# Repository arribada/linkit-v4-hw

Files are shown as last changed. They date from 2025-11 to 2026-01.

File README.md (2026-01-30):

N|Solid

Collaboration with 

N|Solid

# Altium project for Linkit-v4 product

Linkit V4 is the fourth generation of the Linkit tracker CORE board, developed in collaboration with CLS (Collecte Localisation Satellites). This revision transitions from the discontinued ARTIC R3 transceiver to next-generation satellite communication modules, ensuring long-term availability for Argos/Kineis satellite networks.

## Hardware Variants

This project contains **two hardware variants** maintained in separate branches:

### linkit-v4-kim (Branch: `linkit-v4-kim`)
Based on the **KIM2 module** from CLS/Kineis for satellite uplink communication.
- Uses KIM2 satellite modem module
- Certified for Kineis satellite network
- See KIM2 Integration Manual (contact CLS)

### linkit-v4-smd (Branch: `linkit-v4-smd`)
Based on the **Argos-SMD module** - an open-source alternative.
- Compatible with Arribada's Argos-SMD hardware: https://github.com/arribada/argos-smd-hw
- Provides flexibility for custom satellite communication implementations
- Additional power management circuitry for SMD module
- Check [argos-smd-hw repository](github.com/arribada/argos-smd-hw)

The master branch contains a board with both footprints on the same layout, but it is not up to date and may be missing recent changes (deprecated branch).

## Features

### Core Specifications
- **MCU**: ISP1807 (nRF52840-based module)
- **GNSS**: u-blox SAM-M10Q with integrated ceramic antenna
- **Flash Memory**: IS25LP128F (128 Mbit NOR Flash)
- **IMU**: BMA400 ultra-low power accelerometer
- **ADC**: ADS1115 16-bit, 4-channel (for external sensors)

### Power Management
- **Battery**: Single-cell Li-Ion/LiPo (3.7V, 4.2V max)
- **Charging Options**:
  - USB Type-C (BQ25176M linear charger, 800mA)
  - Qi Wireless charging (BQ51003, 2.5W)
  - Solar panel input (3-18V via BQ25176M MPPT-compatible input)
- **Voltage Regulation**: 
  - TPS63901 Buck/Boost (configurable 1.8V/3.3V for main system)
  - TPS612997 Buck/Boost (3.6V for satellite module - SMD variant)
  - TPS22960 dual load switches for power domain control
- **Ultra-low power design**: Sub-microamp quiescent current in sleep modes

### Connectivity & Interfaces
- **Satellite Communication**: KIM2 or Argos-SMD module (variant-dependent)
- **GNSS**: Integrated u-blox M10Q receiver
- **External I/O**:
  - 8-pin expansion connector (1.25mm pitch)
  - External I2C bus for sensors
  - Salt-water switch (SWS) interface
  - Battery voltage monitoring
  - Pressure sensor support via ADC channels
- **Programming/Debug**: 
  - Dual JTAG connectors (ISP1807 + Satellite module)
  - USB-C for firmware updates and charging

### Physical
- Compact form factor optimized for marine deployments
- Reed switch for magnetic activation
- Tri-color LED status indicator
- U.FL/SMA antenna connector options

## Configuration Options

No jumper directly on board, represented by component Resistors or Diode.

### Power Source Selection
The board supports multiple power configurations via resistor options:

1. **Standard Operation** (Default):
   - Battery + USB/Wireless charging + optional solar input
   - All power sources can coexist safely

2. **USB-Only Power** (No Battery):
   - Configuration: R53=DNP, R52=Fitted, R55=Fitted
   - ⚠️ **Warning**: Do NOT connect battery in this mode
   - ⚠️ **Warning**: Power LED D2 incompatible with 5V - cut trace O9 (Not critical)

### Voltage Selection
- **PSEL Pin (TPS63901)**: Switches between 1.8V and 3.3V system voltage
  - Low = 2.3V (minimum voltage for IS25LP Flash and ADC)
  - High = 3.3V (default for most operations)

### Reed Switch
- Magnetic activation via P-channel MOSFET (Q4)
- Can be controlled via MCU or magnetically triggered
- 3.3V logic level compatible

## Operating Modes

### Charging Modes
The tri-color LED (D2) indicates charging status:
- **OFF**: Battery only, no charging
- **Yellow**: Charging via USB
- **White/Cyan**: Charging via wireless coil
- **Green**: Fully charged
- **Blinking Green**: Fault condition (thermal, timer, over-voltage)

## Firmware (still in development)
Firmware is not released as open source at the moment.
- Firmware based on Linkit-v3 Baremetal : https://github.com/arribada/linkit-v4-core
- Zephyr firmware : https://github.com/arribada/linkitv4

## Hardware References (Previous Versions)

Linkit V4 is the successor of previous Linkit CORE board generations developed by Arribada.  
Earlier versions were based on different satellite transceivers and power architectures.

- **Linkit V3**
  - Based on the ARTIC R2/R3 satellite transceiver (now discontinued)
  - Earlier GNSS and power management architectures
  - Designed for Argos satellite network compatibility
  - Links:
    - Hardware github : https://github.com/arribada/CLS-Argos-Linkit-Hardware/
    - Firmware project : [CLS-Argos-Linkit-CORE](https://github.com/arribada/CLS-Argos-Linkit-CORE)
    - Python application : [CLS-Argos-Linkit-pylinkit](https://github.com/arribada/CLS-Argos-Linkit-pylinkit)
    - Phone application : [GenTracker](https://play.google.com/store/apps/details?id=com.trackgen&hl=fr&gl=US&pli=1) available on the store

These earlier designs are no longer actively maintained but are provided for reference and historical context.

## Known Issues & Design Notes

### Issues to Address in Next Revision

⚠️ The **Issues** section of this GitHub repository lists all fixes that need to be applied for the next batch, or by anyone who wants to design or reuse parts of this project.

## License

This project contains hardware design files only.

All hardware design files (schematics, PCB layouts, Altium project files)
are licensed under the **CERN Open Hardware Licence v1.2 (CERN-OHL v1.2)**.

See the `LICENSE` file for the full license text.

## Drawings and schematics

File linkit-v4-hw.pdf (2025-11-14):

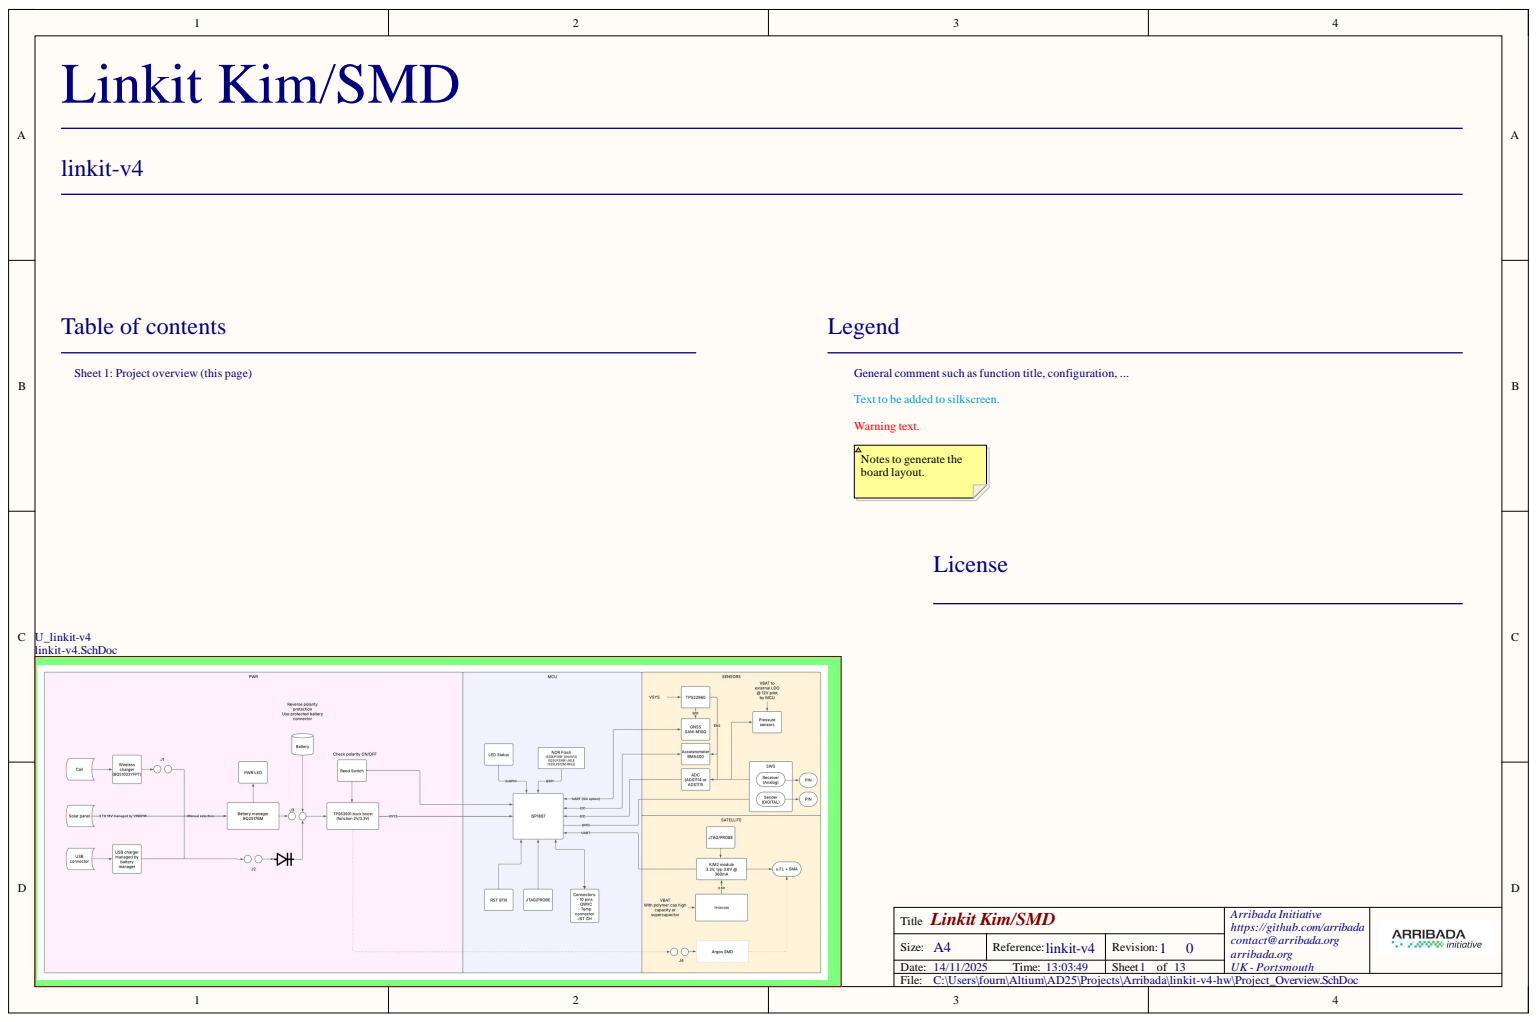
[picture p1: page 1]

Sheet 1: Project overview (this page)

General comment such as function title, configuration, ...

Text to be added to silkscreen.

Notes to generate the
board layout.

Arribada Initiative
https://github.com/arribada
contact@arribada.org
arribada.org

C:\Users\fourn\Altium\AD25\Projects\Arribada\linkit-v4-hw\Project_Overview.SchDoc

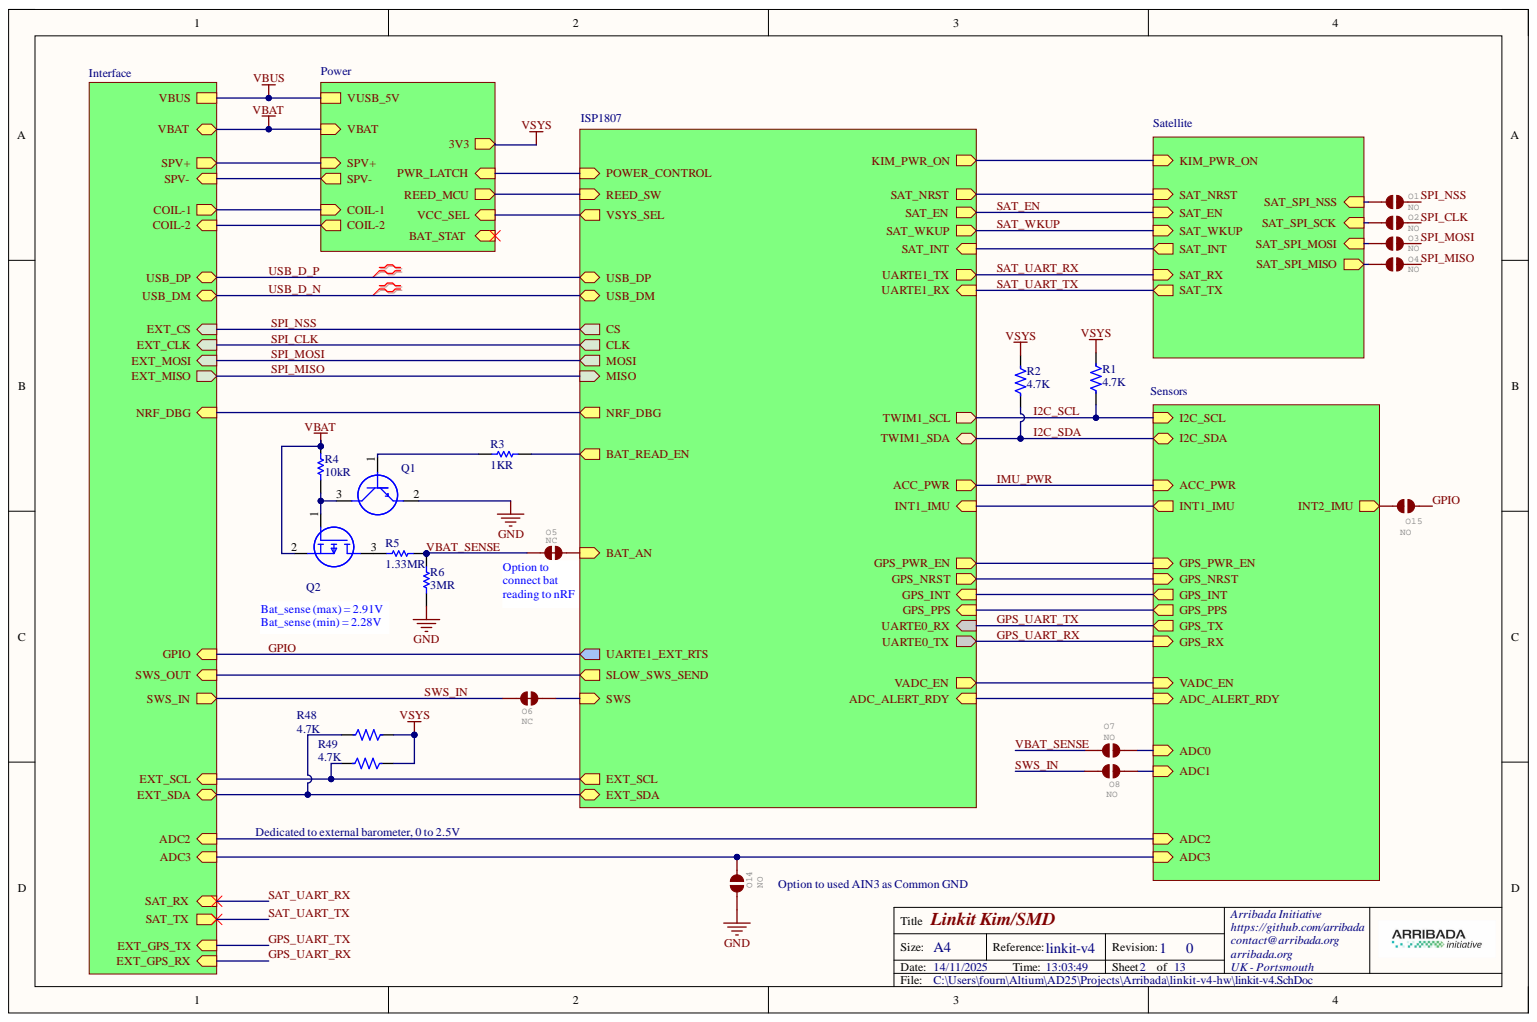
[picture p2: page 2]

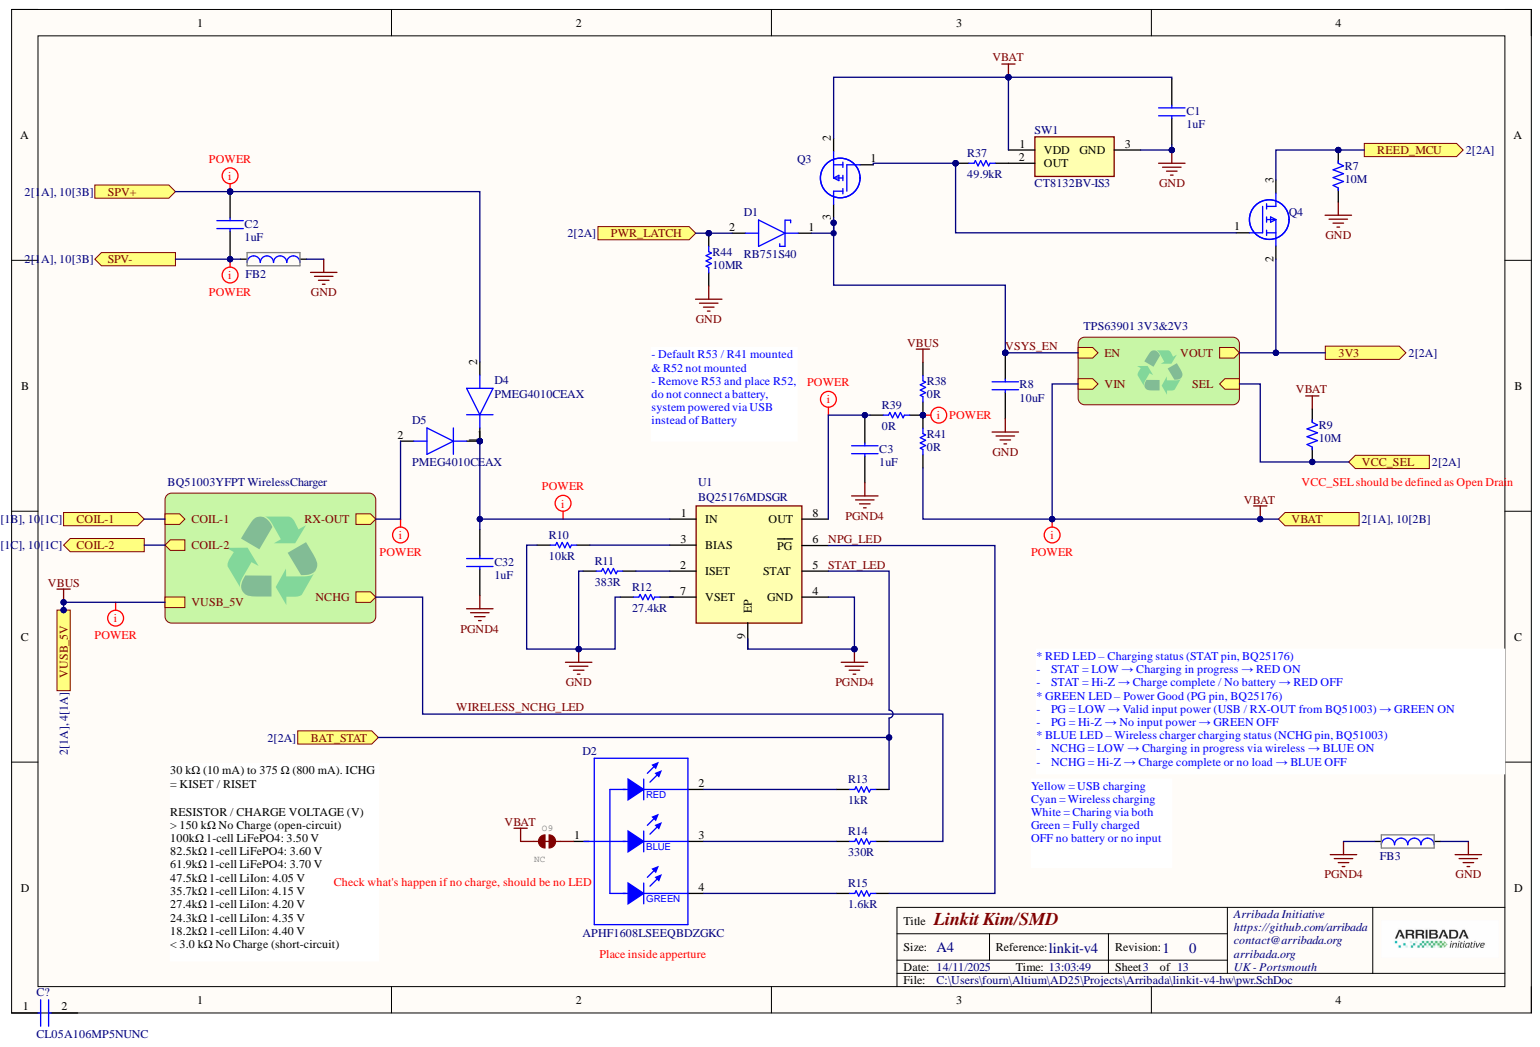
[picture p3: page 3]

& R52 not mounted
- Remove R53 and place R52,
do not connect a battery,
system powered via USB
instead of Battery

VCC_SELshould be defined as Open Drain

* RED LED – Charging status (STAT pin, BQ25176)
- STAT = LOW → Charging in progress → RED ON
- STAT = Hi-Z → Charge complete / No battery → RED OFF
* GREEN LED – Power Good (PG pin, BQ25176)
- PG = LOW → Valid input power (USB / RX-OUT from BQ51003) → GREEN ON
- PG = Hi-Z → No input power → GREEN OFF
* BLUE LED – Wireless charger charging status (NCHG pin, BQ51003)
- NCHG = LOW → Charging in progress via wireless → BLUE ON
- NCHG = Hi-Z → Charge complete or no load → BLUE OFF

30 kΩ (10 mA) to 375 Ω (800 mA). ICHG
= KISET / RISET

Yellow = USB charging
Cyan = Wireless charging
White = Charing via both
Green = Fully charged
OFF no battery or no input

RESISTOR / CHARGE VOLTAGE (V)
> 150 kΩ No Charge (open-circuit)
100kΩ 1-cell LiFePO4: 3.50 V
82.5kΩ 1-cell LiFePO4: 3.60 V
61.9kΩ 1-cell LiFePO4: 3.70 V
47.5kΩ 1-cell LiIon: 4.05 V
35.7kΩ 1-cell LiIon: 4.15 V
27.4kΩ 1-cell LiIon: 4.20 V
24.3kΩ 1-cell LiIon: 4.35 V
18.2kΩ 1-cell LiIon: 4.40 V
< 3.0 kΩ No Charge (short-circuit)

Check what's happen if no charge, should be no LED

Linkit Kim/SMD Title | Arribada Initiative https://github.com/arribada contact@arribada.org arribada.org

A4 Size: | Reference: linkit-v4 | 0 Revision: 1

C:\Users\fourn\Altium\AD25\Projects\Arribada\linkit-v4-hw\pwr.SchDoc

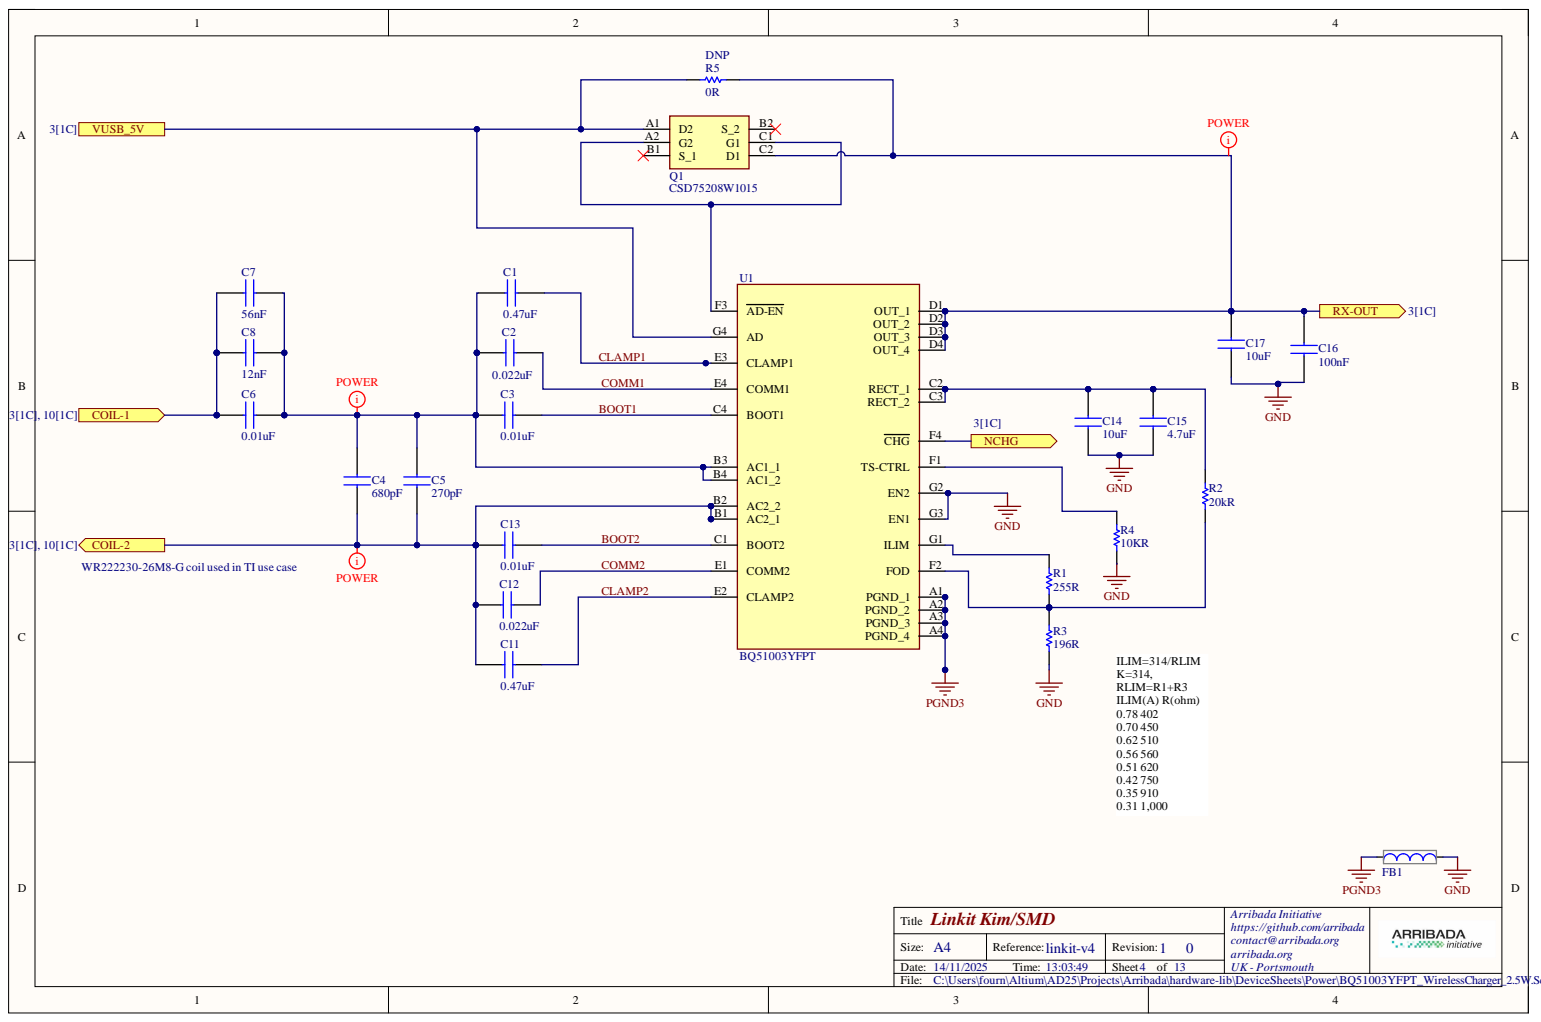
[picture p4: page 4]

CLAMP1

COMM1 | | COMM1 E4

BOOT1 C4 | 3[1C] C14 | C15 4.7uF

BOOT2 C1 | GND | R4 10KR 255R GND

WR222230-26M8-G coil used in TI use case

0.01uF | COMM2 | COMM2 E1

CLAMP2 | | CLAMP2 E2

Arribada Initiative
https://github.com/arribada
contact@arribada.org
arribada.org

C:\Users\fourn\Altium\AD25\Projects\Arribada\hardware-lib\DeviceSheets\Power\BQ51003YFPT_WirelessCharger_2.5W.SchDoc

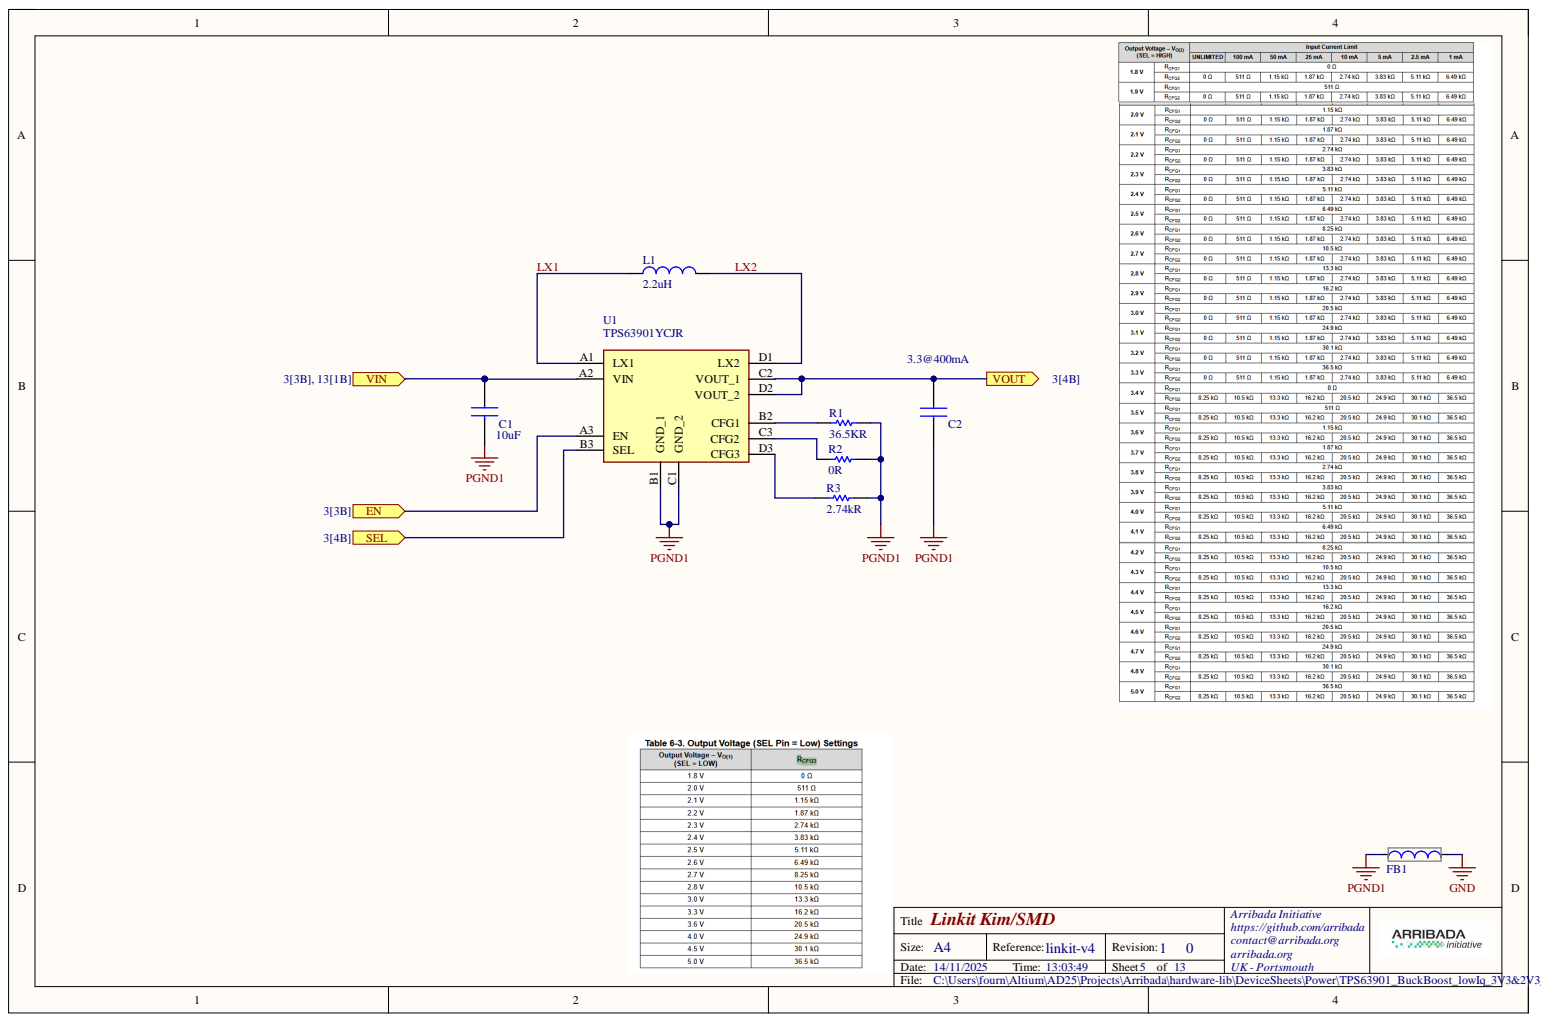
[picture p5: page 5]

Arribada Initiative
https://github.com/arribada
contact@arribada.org
arribada.org

C:\Users\fourn\Altium\AD25\Projects\Arribada\hardware-lib\DeviceSheets\Power\TPS63901_BuckBoost_lowIq_3V3&2V3_400mA.SchDoc

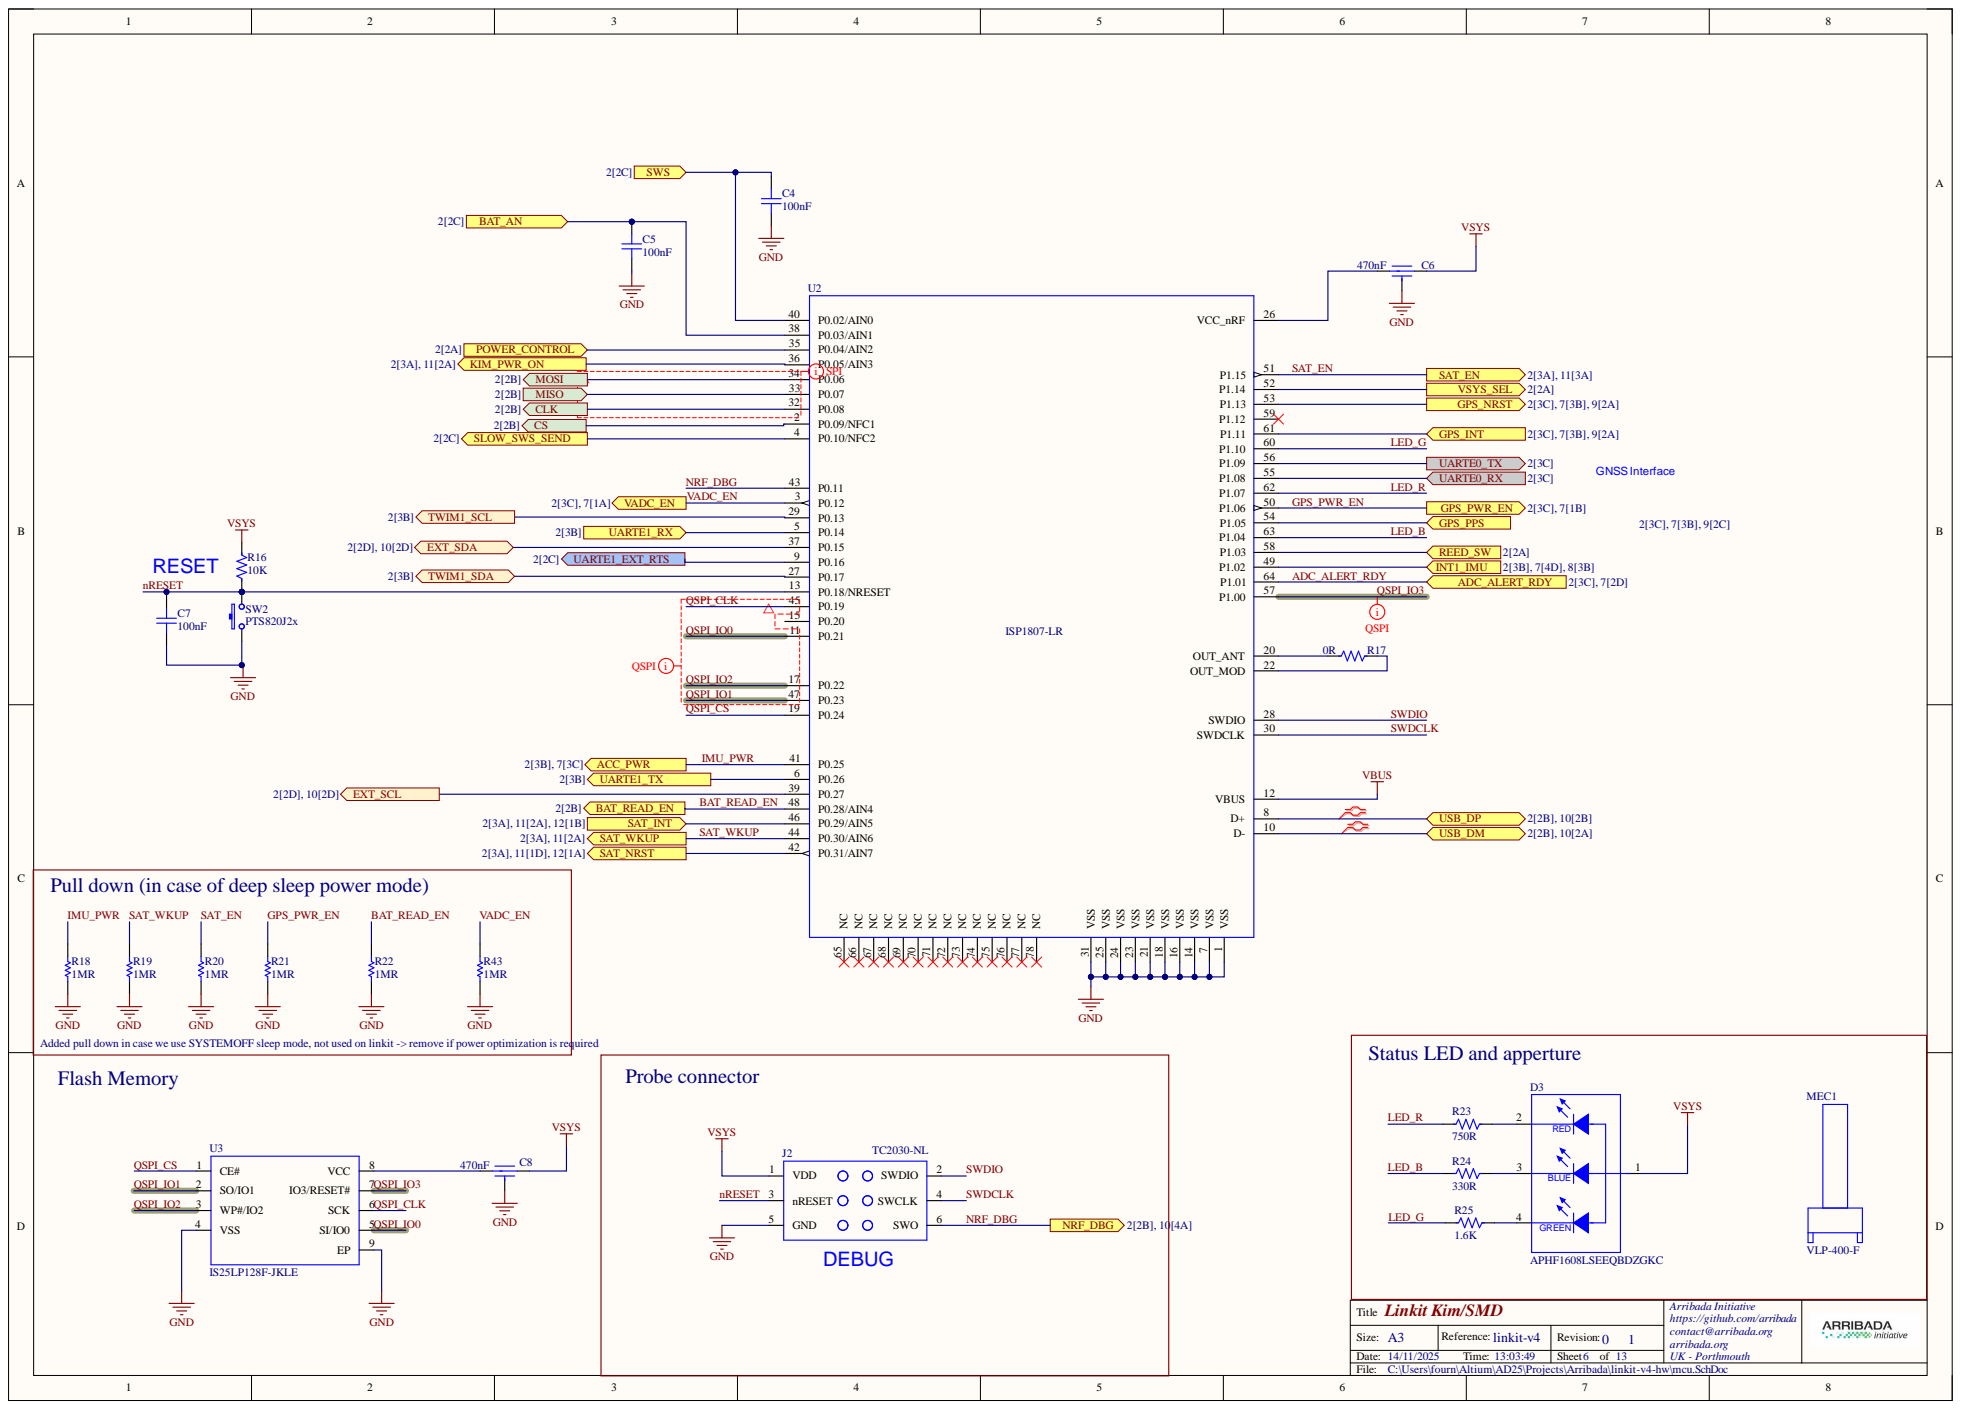
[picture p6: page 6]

Pull down (in case of deep sleep power mode)

GND
Added pull down in case we use SYSTEMOFF sleep mode, not used on linkit -> remove if power optimization is required
Flash Memory

Status LED and apperture

Linkit Kim/SMD Title | Arribada Initiative https://github.com/arribada contact@arribada.org arribada.org UK - Porthmouth

Size: A3 | Reference: linkit-v4 | Revision: 0 1

C:\Users\fourn\Altium\AD25\Projects\Arribada\linkit-v4-hw\mcu.SchDoc

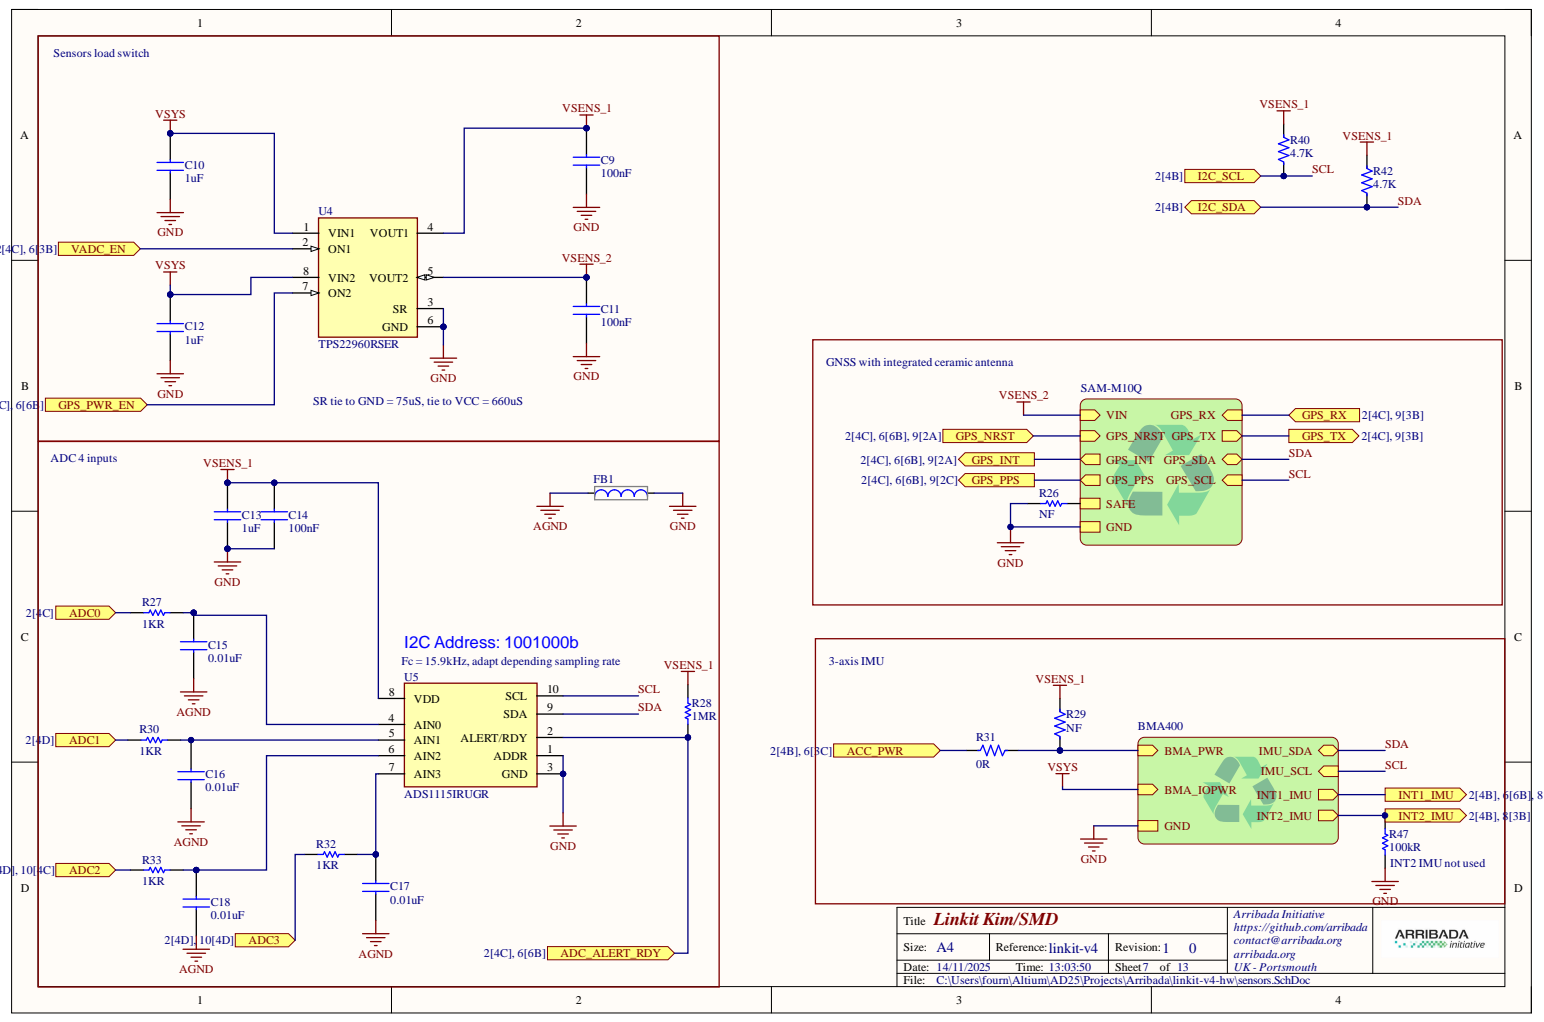
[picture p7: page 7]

GNSS with integrated ceramic antenna

SR tie to GND = 75uS, tie to VCC = 660uS

Linkit Kim/SMD Title | Arribada Initiative https://github.com/arribada contact@arribada.org arribada.org

A4 Size: | Reference: linkit-v4 | 0 Revision: 1

C:\Users\fourn\Altium\AD25\Projects\Arribada\linkit-v4-hw\sensors.SchDoc

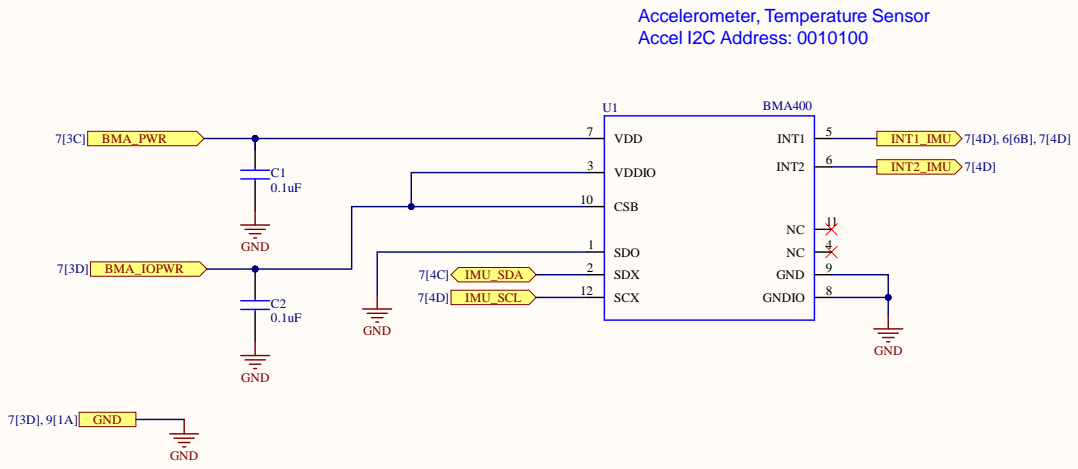
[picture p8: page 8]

7[4 C ] IMU _SD A 1

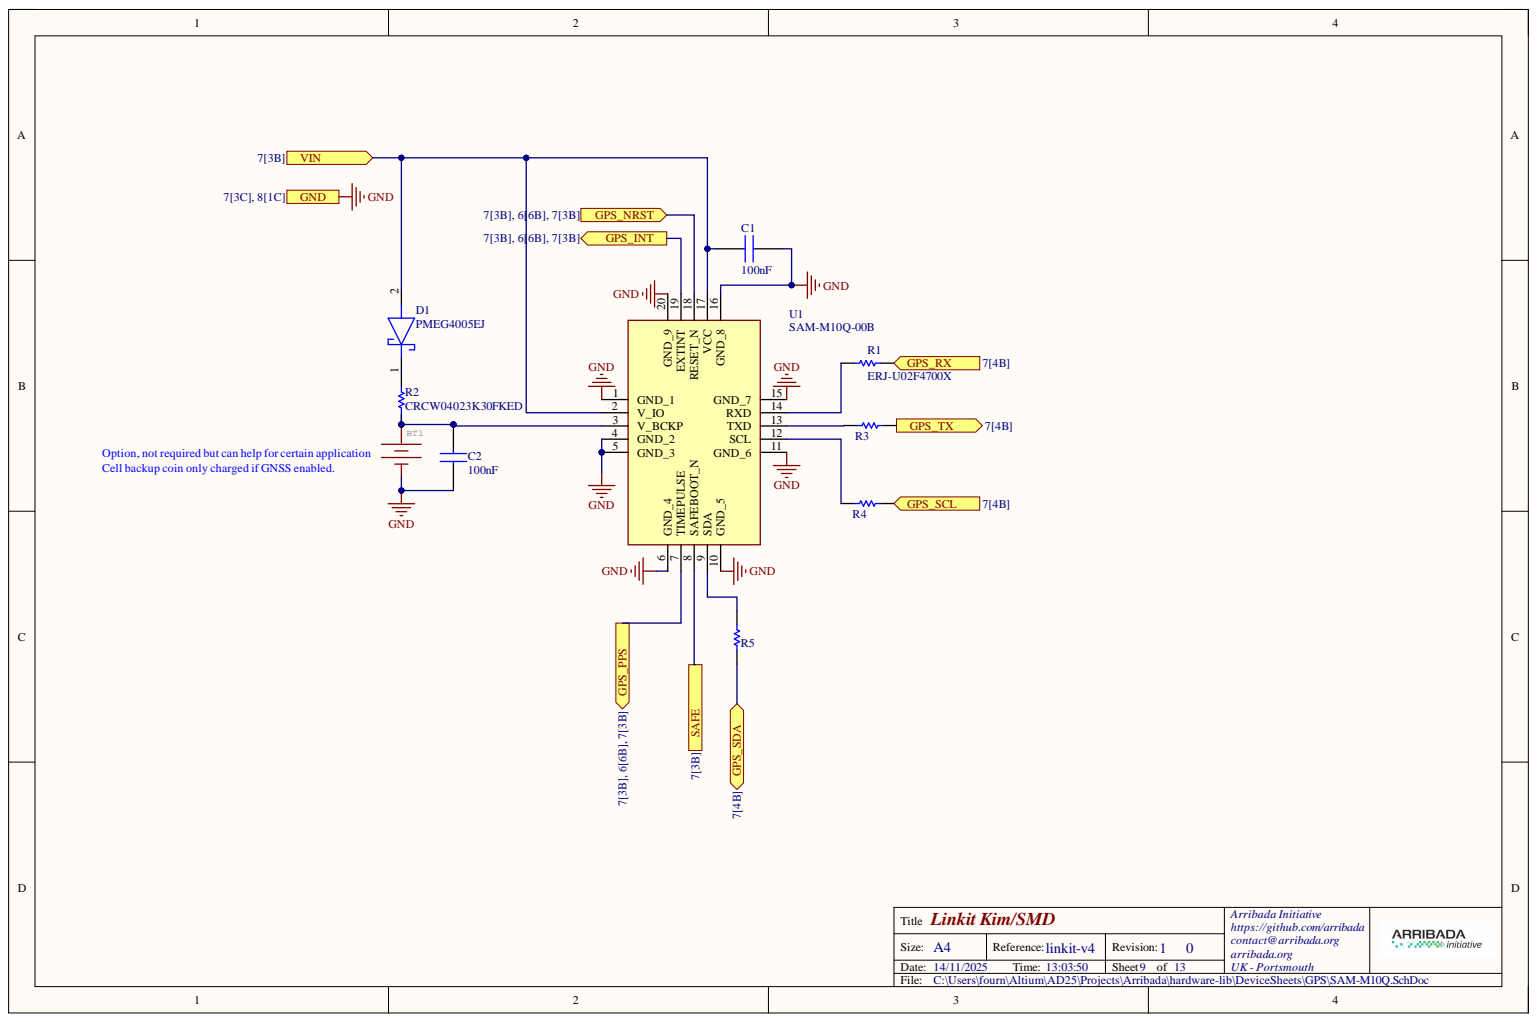
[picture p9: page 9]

D1 PMEG4005EJ R2 CRCW04023K30FKED

V_BCKP 3

Option, not required but can help for certain application
Cell backup coin only charged if GNSS enabled.

Arribada Initiative
https://github.com/arribada
contact@arribada.org
arribada.org

C:\Users\fourn\Altium\AD25\Projects\Arribada\hardware-lib\DeviceSheets\GPS\SAM-M10Q.SchDoc

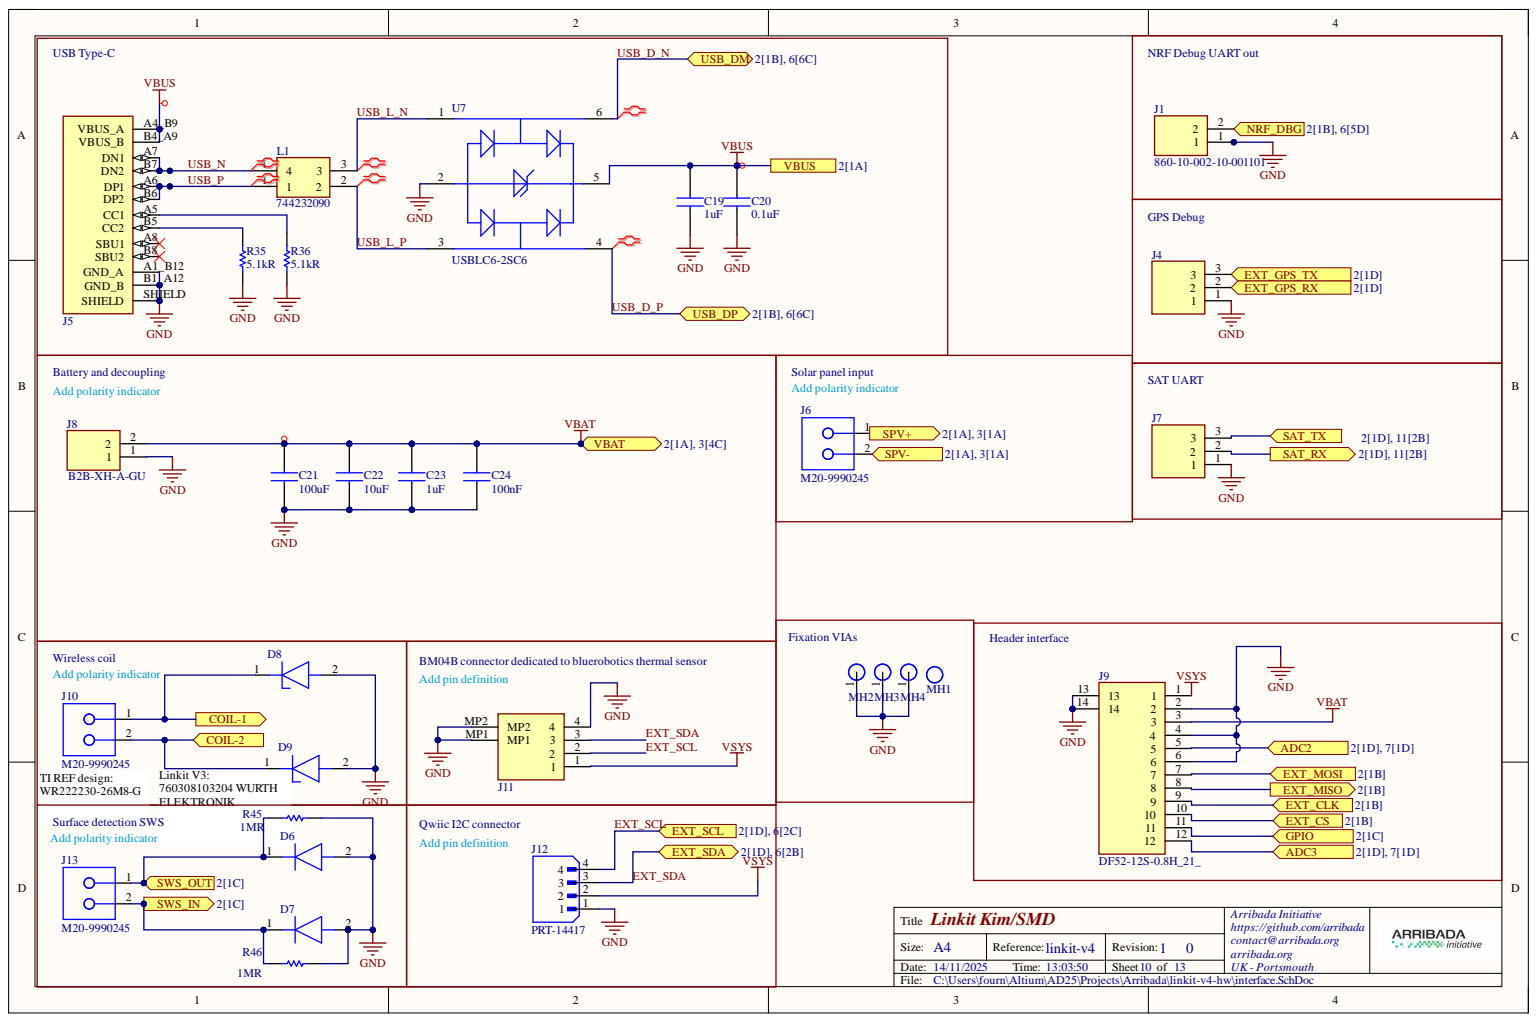
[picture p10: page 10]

NRF Debug UART out

BM04B connector dedicated to bluerobotics thermalsensor
Add pin definition

Arribada Initiative
https://github.com/arribada
contact@arribada.org
arribada.org

C:\Users\fourn\Altium\AD25\Projects\Arribada\linkit-v4-hw\interface.SchDoc

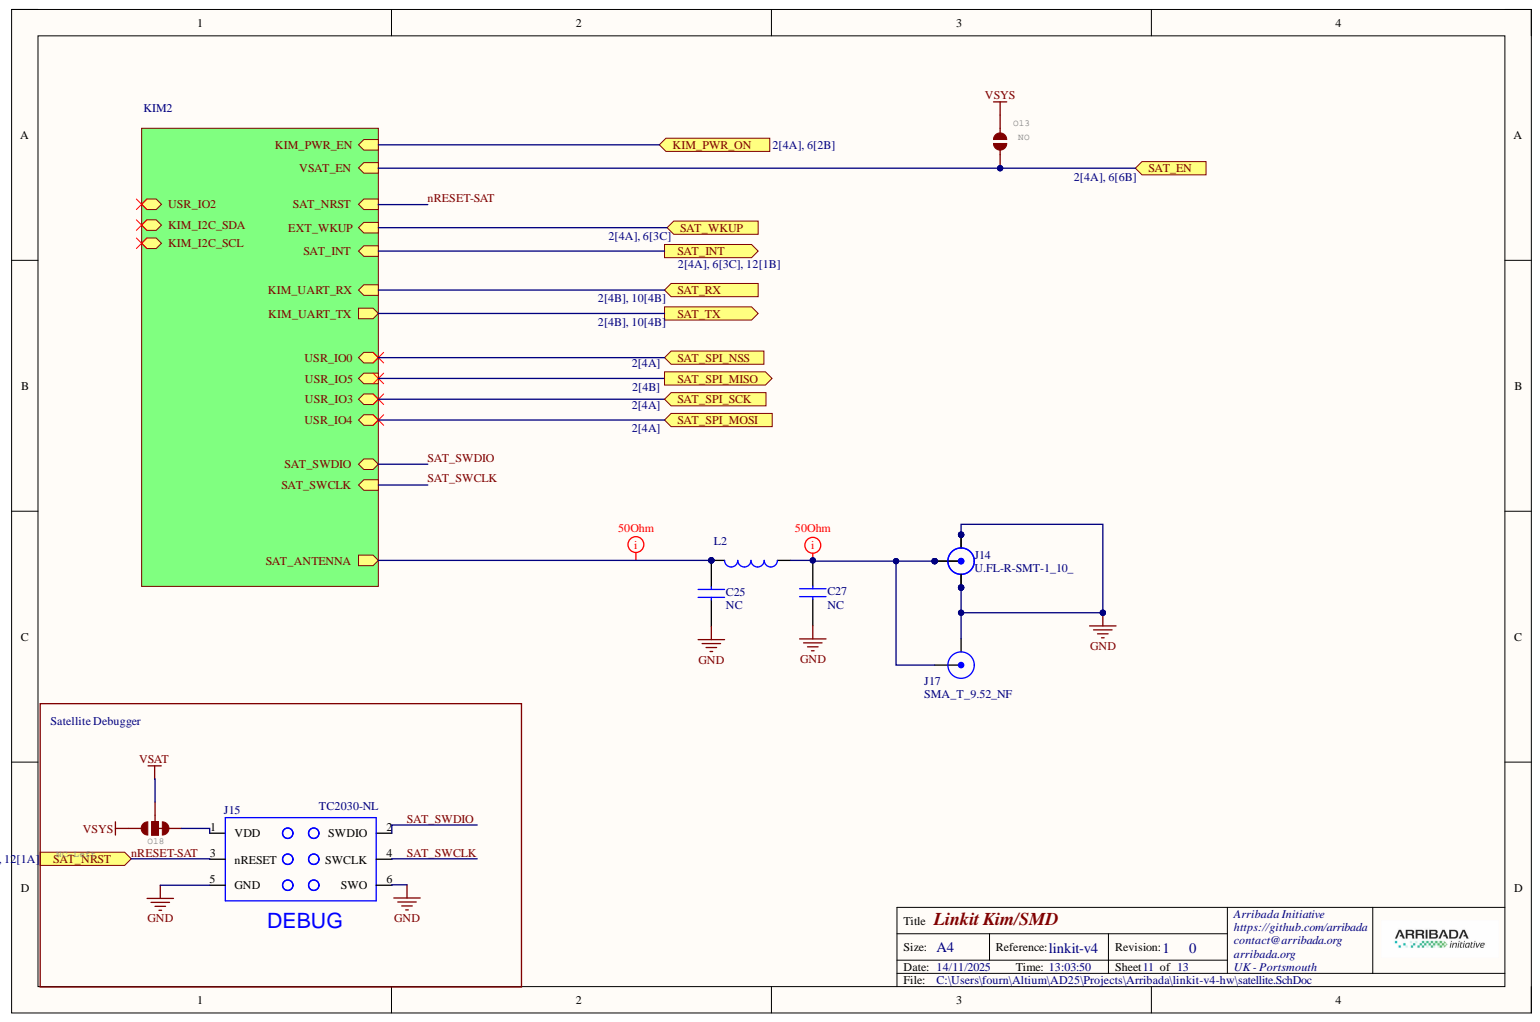
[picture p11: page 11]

Arribada Initiative
https://github.com/arribada
contact@arribada.org
arribada.org

C:\Users\fourn\Altium\AD25\Projects\Arribada\linkit-v4-hw\satellite.SchDoc

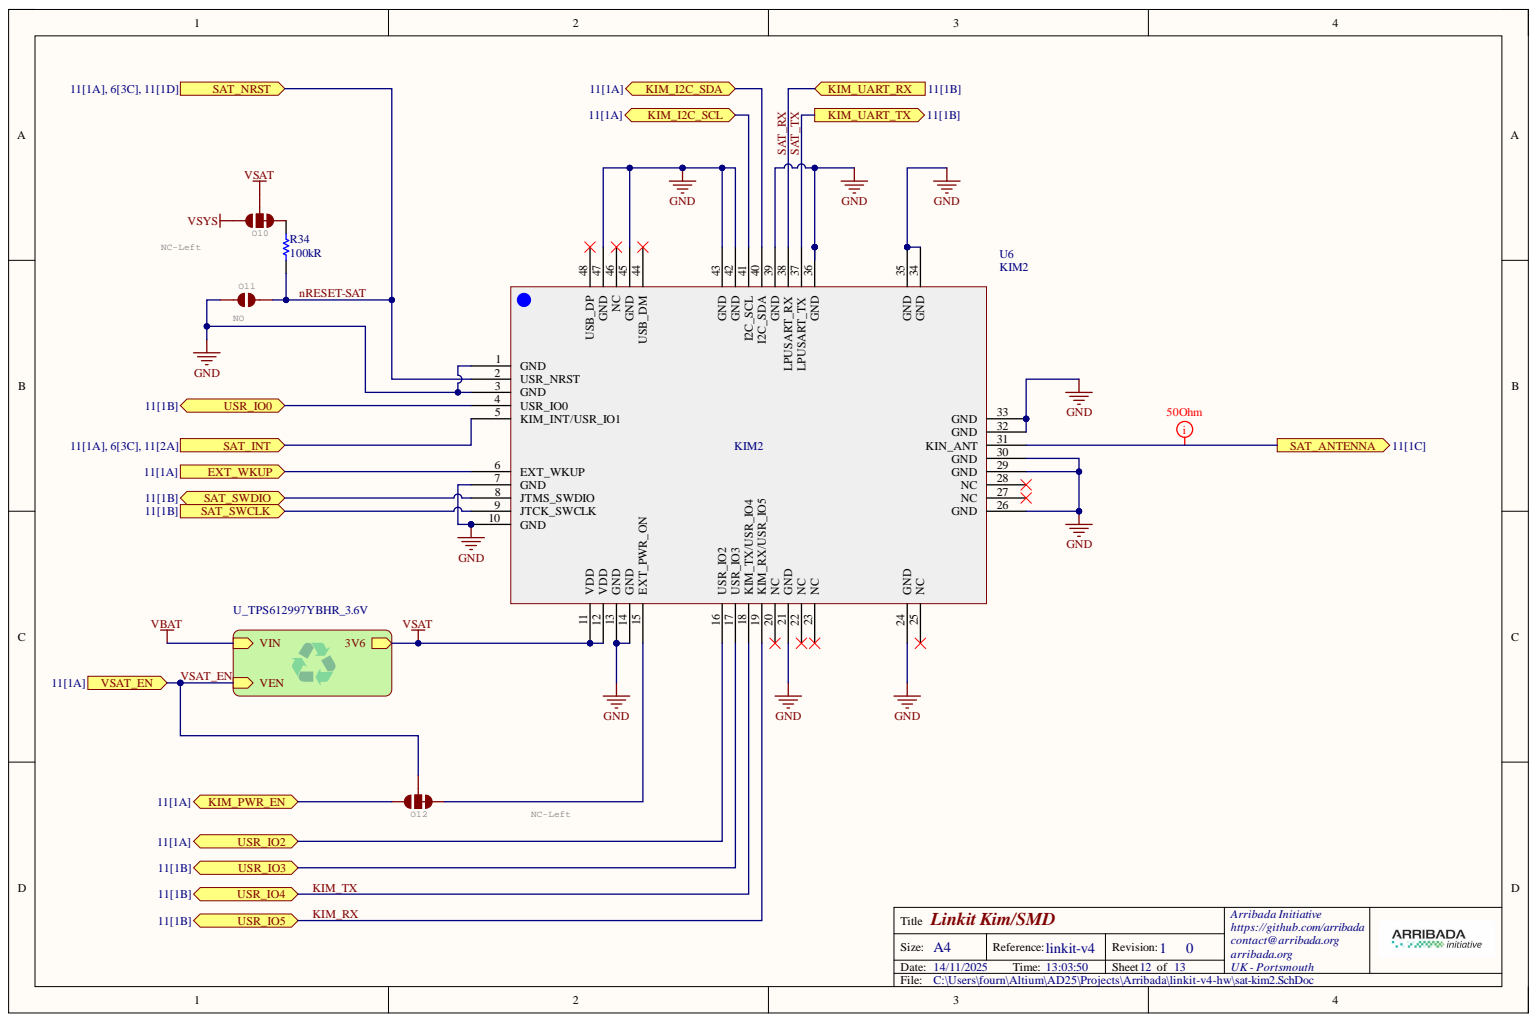
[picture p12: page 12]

Arribada Initiative
https://github.com/arribada
contact@arribada.org
arribada.org

C:\Users\fourn\Altium\AD25\Projects\Arribada\linkit-v4-hw\sat-kim2.SchDoc


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

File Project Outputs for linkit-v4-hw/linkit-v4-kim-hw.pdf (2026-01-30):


Sheet 1: Project overview (this page)

General comment such as function title, configuration, ...

Text to be added to silkscreen.

Notes to generate the
board layout.

Arribada Initiative
https://github.com/arribada
contact@arribada.org
arribada.org

C:\Users\fourn\Altium\AD25\Projects\Arribada\linkit-v4-hw\Project_Overview.SchDoc



& R52 not mounted
- Remove R53 and place R52,
do not connect a battery,
system powered via USB
instead of Battery

VCC_SELshould be defined as Open Drain

* RED LED – Charging status (STAT pin, BQ25176)
- STAT = LOW → Charging in progress → RED ON
- STAT = Hi-Z → Charge complete / No battery → RED OFF
* GREEN LED – Power Good (PG pin, BQ25176)
- PG = LOW → Valid input power (USB / RX-OUT from BQ51003) → GREEN ON
- PG = Hi-Z → No input power → GREEN OFF
* BLUE LED – Wireless charger charging status (NCHG pin, BQ51003)
- NCHG = LOW → Charging in progress via wireless → BLUE ON
- NCHG = Hi-Z → Charge complete or no load → BLUE OFF

30 kΩ (10 mA) to 375 Ω (800 mA). ICHG
= KISET / RISET

Yellow = USB charging
Cyan = Wireless charging
White = Charing via both
Green = Fully charged
OFF no battery or no input

RESISTOR / CHARGE VOLTAGE (V)
> 150 kΩ No Charge (open-circuit)
100kΩ 1-cell LiFePO4: 3.50 V
82.5kΩ 1-cell LiFePO4: 3.60 V
61.9kΩ 1-cell LiFePO4: 3.70 V
47.5kΩ 1-cell LiIon: 4.05 V
35.7kΩ 1-cell LiIon: 4.15 V
27.4kΩ 1-cell LiIon: 4.20 V
24.3kΩ 1-cell LiIon: 4.35 V
18.2kΩ 1-cell LiIon: 4.40 V
< 3.0 kΩ No Charge (short-circuit)

Check what's happen if no charge, should be no LED

Linkit Kim/SMD Title | Arribada Initiative https://github.com/arribada contact@arribada.org arribada.org

A4 Size: | Reference: linkit-v4 | 0 Revision: 1

C:\Users\fourn\Altium\AD25\Projects\Arribada\linkit-v4-hw\pwr.SchDoc


CLAMP1

COMM1 | | COMM1 E4

BOOT1 C4 | 3[1C] C14 | C15 4.7uF

BOOT2 C1 | GND | R4 10KR 255R GND

WR222230-26M8-G coil used in TI use case

0.01uF | COMM2 | COMM2 E1

CLAMP2 | | CLAMP2 E2

Arribada Initiative
https://github.com/arribada
contact@arribada.org
arribada.org

C:\Users\fourn\Altium\AD25\Projects\Arribada\hardware-lib\DeviceSheets\Power\BQ51003YFPT_WirelessCharger_2.5W.SchDoc


Arribada Initiative
https://github.com/arribada
contact@arribada.org
arribada.org

C:\Users\fourn\Altium\AD25\Projects\Arribada\hardware-lib\DeviceSheets\Power\TPS63901_BuckBoost_lowIq_3V3&2V3_400mA.SchDoc


Pull down (in case of deep sleep power mode)

GND
Added pull down in case we use SYSTEMOFF sleep mode, not used on linkit -> remove if power optimization is required
Flash Memory

Status LED and apperture

Linkit Kim/SMD Title | Arribada Initiative https://github.com/arribada contact@arribada.org arribada.org UK - Porthmouth

Size: A3 | Reference: linkit-v4 | Revision: 0 1

C:\Users\fourn\Altium\AD25\Projects\Arribada\linkit-v4-hw\mcu.SchDoc


GNSS with integrated ceramic antenna

SR tie to GND = 75uS, tie to VCC = 660uS

Linkit Kim/SMD Title | Arribada Initiative https://github.com/arribada contact@arribada.org arribada.org

A4 Size: | Reference: linkit-v4 | 0 Revision: 1

C:\Users\fourn\Altium\AD25\Projects\Arribada\linkit-v4-hw\sensors.SchDoc


7[4 C ] IMU _SD A 1


D1 PMEG4005EJ R2 CRCW04023K30FKED

V_BCKP 3

Option, not required but can help for certain application
Cell backup coin only charged if GNSS enabled.

Arribada Initiative
https://github.com/arribada
contact@arribada.org
arribada.org

C:\Users\fourn\Altium\AD25\Projects\Arribada\hardware-lib\DeviceSheets\GPS\SAM-M10Q.SchDoc


NRF Debug UART out

BM04B connector dedicated to bluerobotics thermalsensor
Add pin definition

Arribada Initiative
https://github.com/arribada
contact@arribada.org
arribada.org

C:\Users\fourn\Altium\AD25\Projects\Arribada\linkit-v4-hw\interface.SchDoc


Arribada Initiative
https://github.com/arribada
contact@arribada.org
arribada.org

C:\Users\fourn\Altium\AD25\Projects\Arribada\linkit-v4-hw\satellite.SchDoc



Arribada Initiative
https://github.com/arribada
contact@arribada.org
arribada.org

C:\Users\fourn\Altium\AD25\Projects\Arribada\linkit-v4-hw\sat-smd.SchDoc

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

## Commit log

2025-04-28 initial commit with pwr part
    [Project_Overview.SchDoc, linkit-v4-hw.PrjPcb, linkit-v4.SchDoc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]
2025-04-29 All sheet almost done, link in progress, SMD sheet missing
    [Project_Overview.SchDoc, interface.SchDoc, linkit-v4-hw.PrjPcb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]
2025-04-30 First draft almost ready
    - Check ADC voltage range
    - Add reed switch
    - Add SMD
    [interface.SchDoc, linkit-v4-hw.PrjPcb, linkit-v4.SchDoc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]
2025-05-05 First version to review, missing SMD module
    [interface.SchDoc, linkit-v4-hw.PrjPcb, linkit-v4.SchDoc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]
2025-05-09 add SMD and fix error, fix minor error and finalize variant file
    [Project_Overview.SchDoc, interface.SchDoc, linkit-v4-hw.PrjPcb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]
2025-05-13 start fist layout
    [interface.SchDoc, linkit-v4-0.1.PcbDoc, linkit-v4-hw.PrjPcb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]
2025-05-15 update broken link into schematics and fix PCB components import
    [interface.SchDoc, linkit-v4-0.1.PcbDoc, linkit-v4-hw.PrjPcb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]
2025-05-16 Review Susanna and change on power/sat part
    - Add Header for solar PV
    - Add selector between solar or VBUS/COIL
    - Add selector for a mode without BAT connected
    [Project_Overview.SchDoc, interface.SchDoc, linkit-v4-0.1.PcbDoc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]
2025-05-16 minor fix on satellite pi filter + first component draft
    [interface.SchDoc, linkit-v4-0.1.PcbDoc, linkit-v4-hw.PrjPcb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]
2025-05-23 Routing in progress 4-layers
    [Project_Overview.SchDoc, interface.SchDoc, linkit-v4-0.1.PcbDoc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]
2025-05-26 change SPI satellite connection and progress on Layout
    [linkit-v4-0.1.PcbDoc, linkit-v4.SchDoc, sensors.SchDoc]
2025-05-30 change to 6 layer and move some MCU pin attributions
    [interface.SchDoc, linkit-v4-0.1.PcbDoc, linkit-v4-0.1_6layers.PcbDoc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]
2025-06-02 Update BGA nrf
    [linkit-v4-0.2_6layers.PcbDoc]
2025-06-03 First draft in progress, GND and enhancement in progress
    [interface.SchDoc, linkit-v4-0.1_6layers.PcbDoc, linkit-v4-0.2_6layers - Copie.PcbDoc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]
2025-06-10 Update ActiveBom, and first draft almost done
    [interface.SchDoc, linkit-v4-0.2_6layers - Copie.PcbDoc, linkit-v4-0.3_6layers.PcbDoc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]
2025-06-10 adapt vias, stitching and fix error
    [linkit-v4-0.3_6layers.PcbDoc, linkit-v4-hw.PrjPcb]
2025-06-12 Add DeviceSheets copy inside repository
    [BMA400_ACC_LinkitV3.SchDoc, BQ51003YFPT_WirelessCharger_2.5W.SchDoc, SAM-M10Q.SchDoc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]
2025-06-26 Final schematics review and split with KIM ONLY
    [interface.SchDoc, linkit-v4-0.1_6layers.PcbDoc, linkit-v4-0.2_6layers.PcbDoc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]
2025-06-30 Version ready to ask for quotation/production
    [BMA400_ACC_LinkitV3.SchDoc, BQ51003YFPT_WirelessCharger_2.5W.SchDoc, TPS612997YBHR_3.6V_lowIQ_1.9A.SchDoc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]
2025-08-04 Update with H.C.C remarks:
    - Change all blind vias to 0.15mm hole (add for power pather
    more vias)
    - Fix BM04 connector
    - Fix board stackk according to the one provided by H.C.C
    - Fix Impedance line 90R and 50R according to new board stack
    [interface.SchDoc, linkit-v4-0.3_6layers_kimonly.PcbDoc, linkit-v4-hw.PrjPcb]
2025-08-12 Last changes with production review
    [interface.SchDoc, linkit-v4-0.3_6layers_kimonly.PcbDoc, linkit-v4-hw.PrjPcb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]
2025-11-14 update kim-only variant file with latest request to H.C.C
    [linkit-v4-hw.PrjPcb, mcu.SchDoc, pwr.SchDoc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]
2026-01-30 add final gerbers used for production batch 1
